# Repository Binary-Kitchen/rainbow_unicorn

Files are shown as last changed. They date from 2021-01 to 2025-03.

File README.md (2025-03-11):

# Rainbow Unicorn 1

## This repo is archived. New updated version here: https://github.com/blinkyparts/unicorn

This unicorn will bright up your life. The hair is glowing in all colours of the rainbow due to RGB-LEDs on the back. The soldering kit is very simple and easy to assamble.

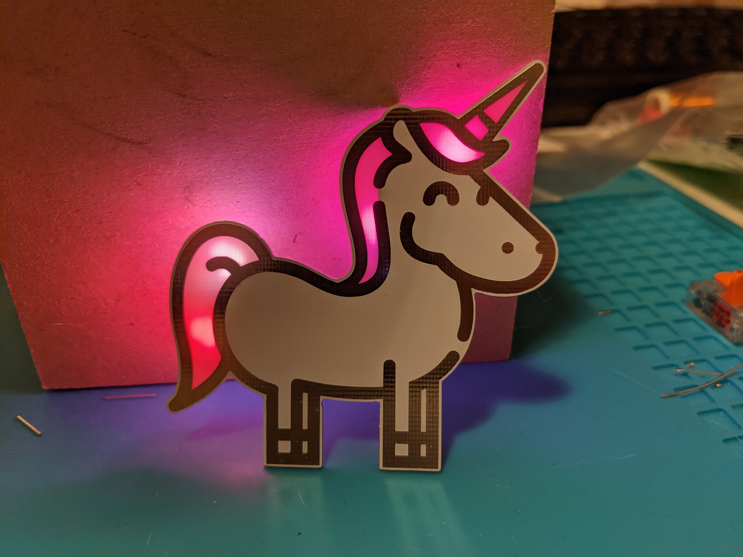
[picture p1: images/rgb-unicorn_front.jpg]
Rainbow Unicorn
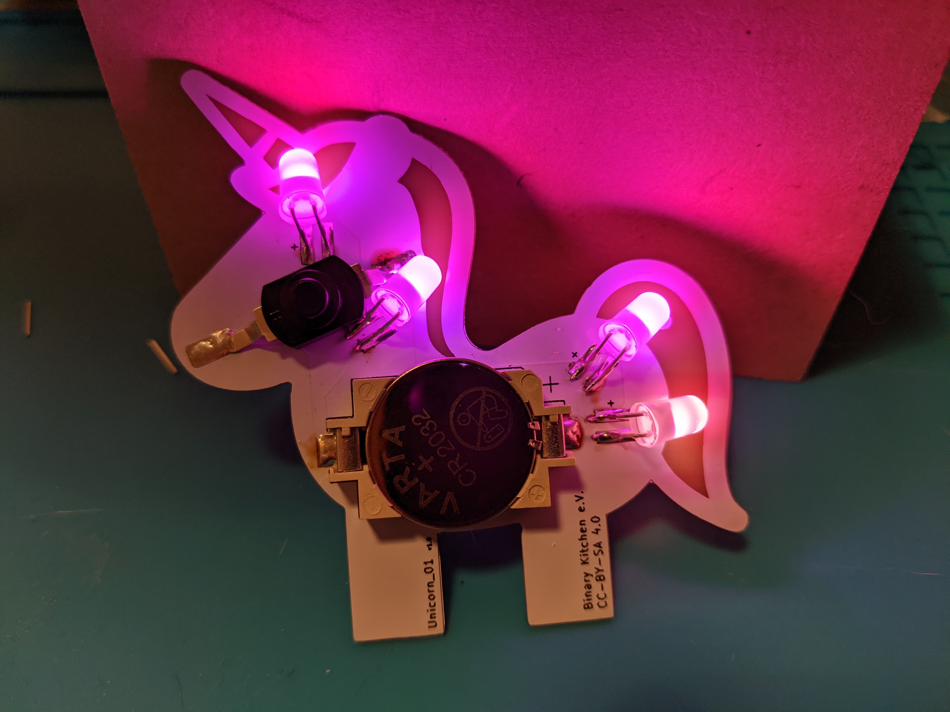
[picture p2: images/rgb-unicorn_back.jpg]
Rainbow Unicorn
 

The RGB-Effect looks like this, but much better in real :)
UniBadge 9x9 creation

- Status: **Complete**
- Difficulty: **2/5**

### Parts List

| Description | Quantity |
|---|---|
| RGB LEDs 5mm | 4 |
| Button (SMD) | 1 |
| CR2032 Battery Holder (SMD) | 1 |
| CR2032 Battery (not included) | 1 |

### Manual
You can find the manual and pictures of every step here: https://github.com/Binary-Kitchen/SolderingTutorial

### Copyright and Authorship

- Board: [CC-BY-SA 4.0](https://creativecommons.org/licenses/by-sa/4.0/) - Binary Kitchen e.V.
- Unicorn SVG [CC-BY-SA](https://creativecommons.org/licenses/by-sa/4.0/) - [Unicorn by Mooms from the Noun Project](https://thenounproject.com/term/unicorn/2061795/) (We've bought a licence, you should honor the artist work too!)
- Idea and scheme: [CC-BY-SA 4.0](https://creativecommons.org/licenses/by-sa/4.0/) - [Elektronikmuseum Tettnang](http://www.emuseum-tettnang.de/)

### Buy Soldering Kits
If you want to buy the parts and PCB for a soldering kit you can find everything here: [shop.blinkyparts.com](https://shop.blinkyparts.com/de/Regenbogen-Einhorn-Einfacher-Bausatz-fuer-einen-tollen-Anstecker/blink232242)

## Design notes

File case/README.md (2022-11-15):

# Case

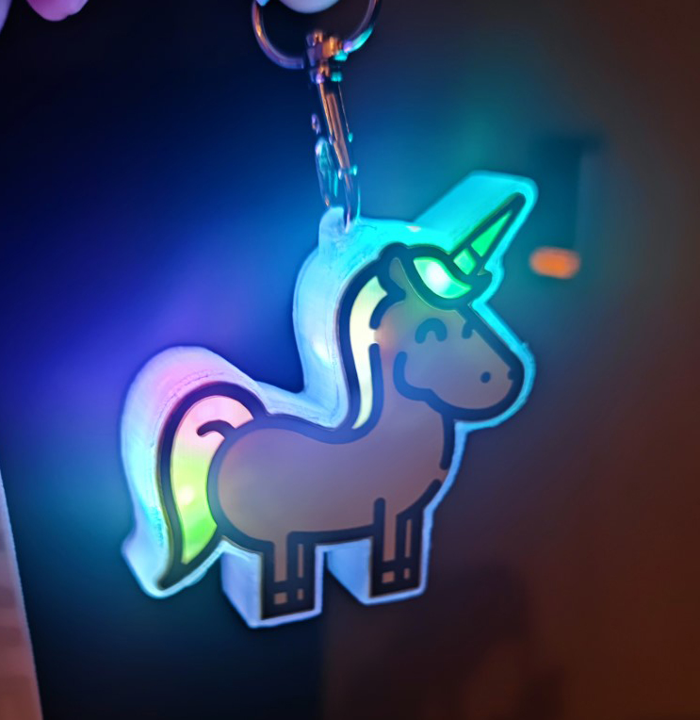
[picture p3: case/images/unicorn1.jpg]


It is recommented to print this case with transparent PET filament.

There are two variants of the case:

* A case consisting of a frame that will be glued to the board, and a separate lid held in place by screws.
* A case consisting of a single body part only, where the board just snaps in. This one is a bit easier to print and assemble, but not quite as sturdy.

## Case with Separate Lid

### Things you'll need

* Transparent Filament
* 6 M1,7*6 screws
* Glue

### Assembly

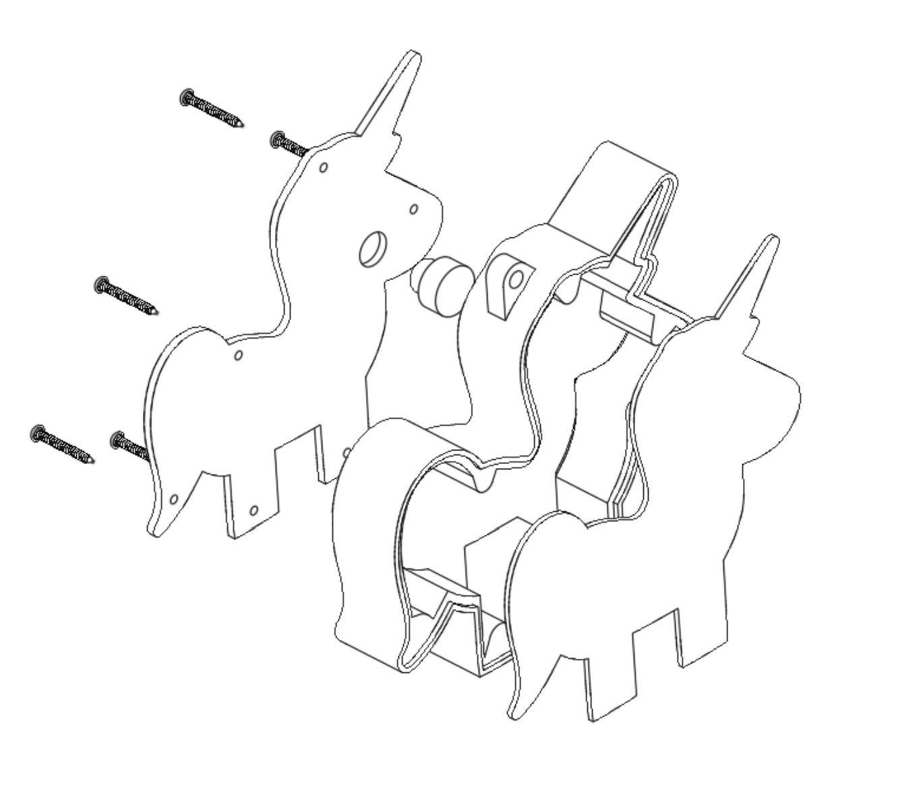
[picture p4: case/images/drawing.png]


First you'll need to print the three parts:

* Outer case
* Button
* Cover

I used generic PET filament at 235°C and a bed temperature of 75°C. Best is to place the case with the screw holes facing towards the build plate and adding a brim for more contact surface.

Then you can glue the PCB to the top part of the outer case. The top part does not have holes for the screws in it. I used hot glue, but the issue was, that the glue was getting hard too fast. I then heated up the PCB with my hot air gun to let the glue get soft again. After that I pressed the PCB and the case together. Maybe some other glue might work better.
With the PCB in place, just add place the button on top of the button on the PCB and carefully place the back cover on top of it. Fix the screws and your all set.

The result will look something like this:

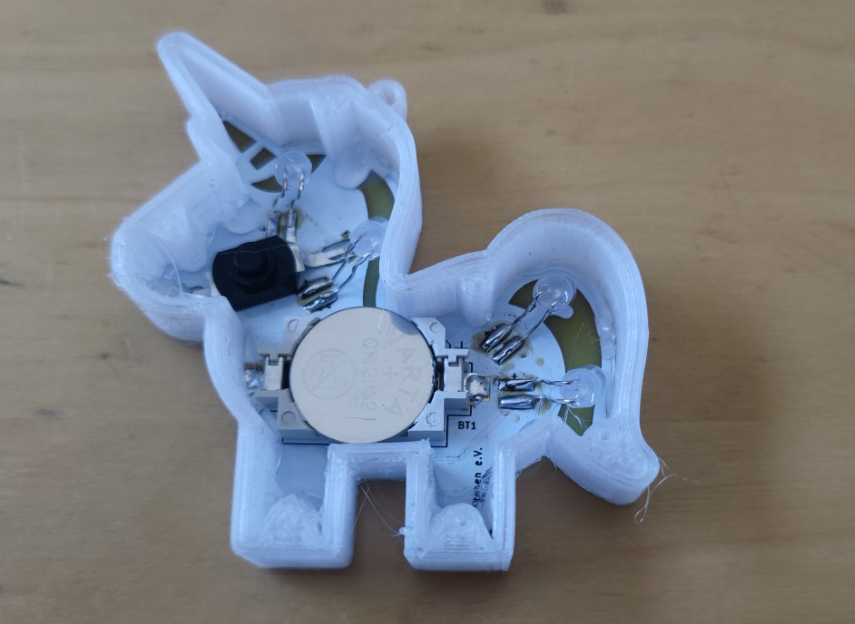
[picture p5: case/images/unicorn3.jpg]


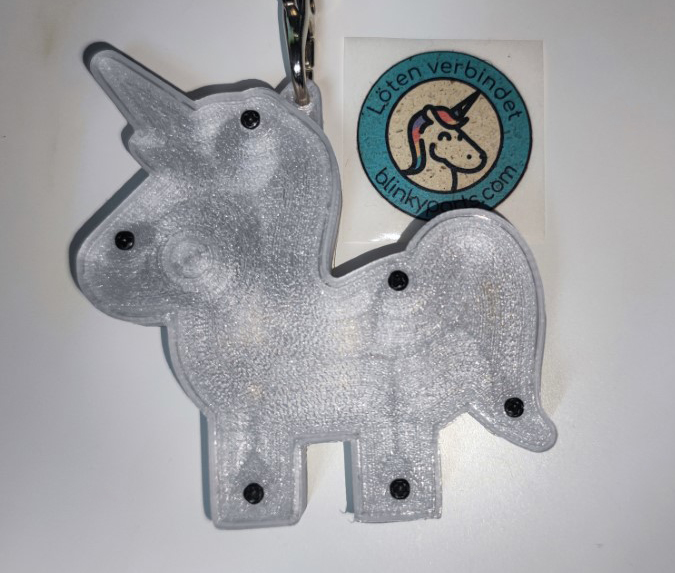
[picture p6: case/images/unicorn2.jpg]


## Snap-fit Case

### Things you'll need

* Transparent filament (preferably PET because it's a bit more flexible)

### Assembly

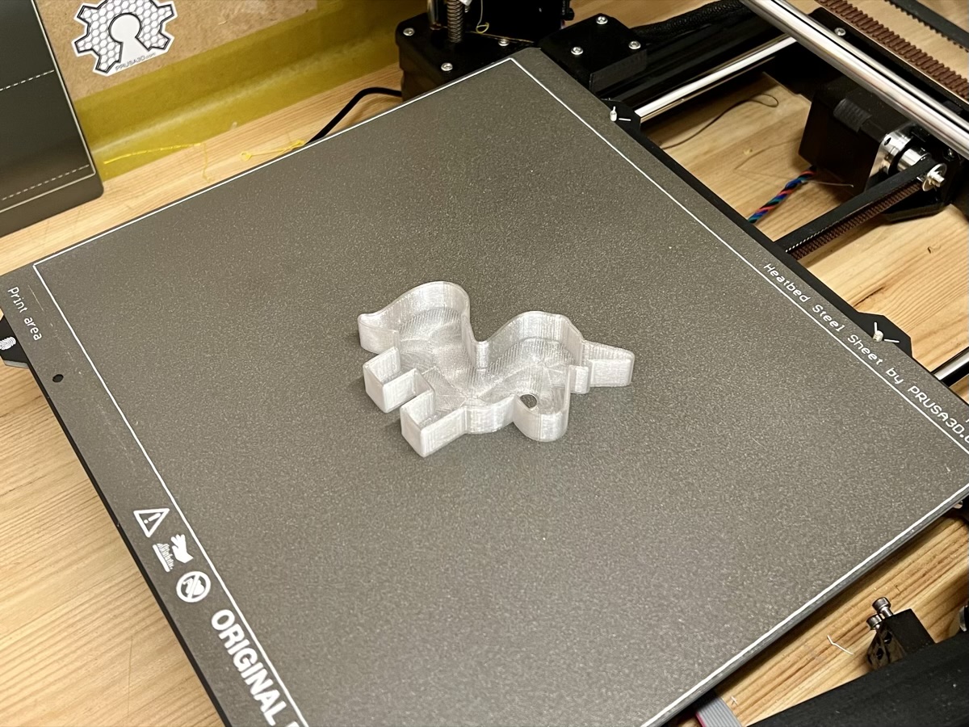
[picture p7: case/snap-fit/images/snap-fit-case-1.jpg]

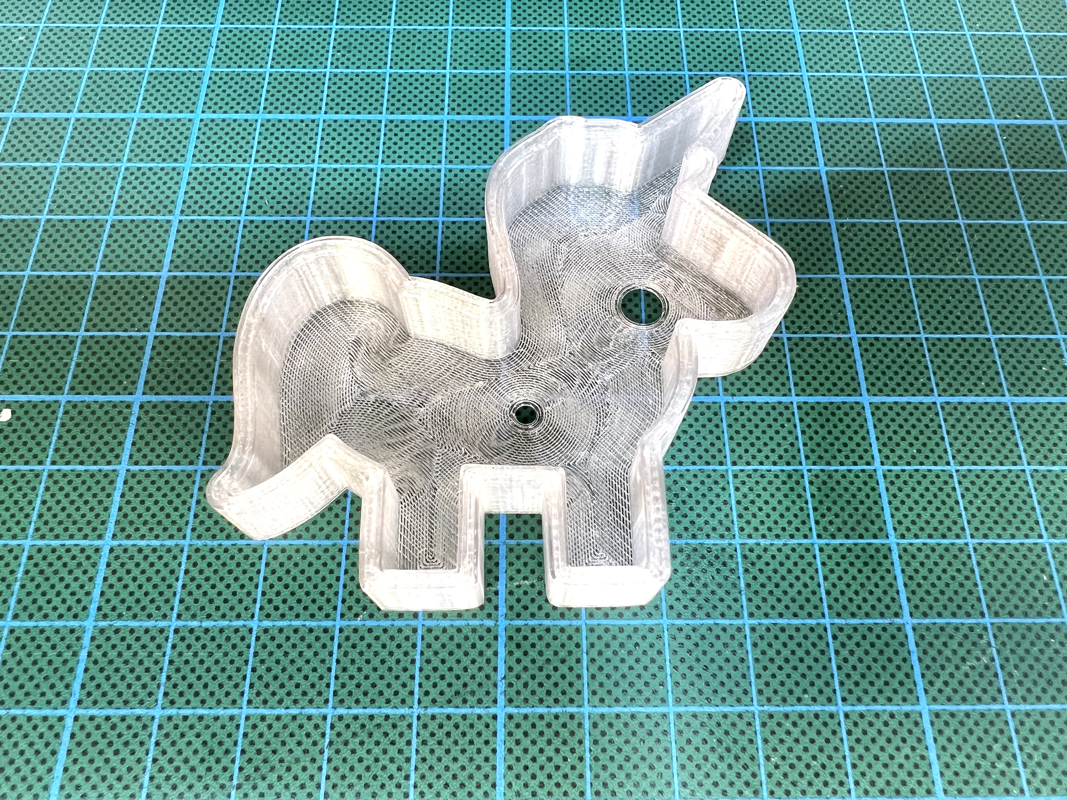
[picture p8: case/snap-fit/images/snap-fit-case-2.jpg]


You need to print the body (either the version with or without hanger) and the button. Print the body with the bottom side facing the print plate (like shown in the photo above), this way no support material and no brim is needed. Use two separate print jobs for body and button if you want to make sure that there is no stringing.

Using the "0.30mm DRAFT" preset in Prusa Slicer seems to work well and results in a print time of about 45 minutes. (I used "concentric" infill for the bottom layer to give it a more interesting look, but of course any infill pattern will work.)

After the print has completed simply insert the button into the hole and then snap the board into place, using gentle force as needed. The fit is rather tight to make sure the board is held in place securely.

If you want to remove the board later just insert a toothpick into the small hole on the back and push the board out.

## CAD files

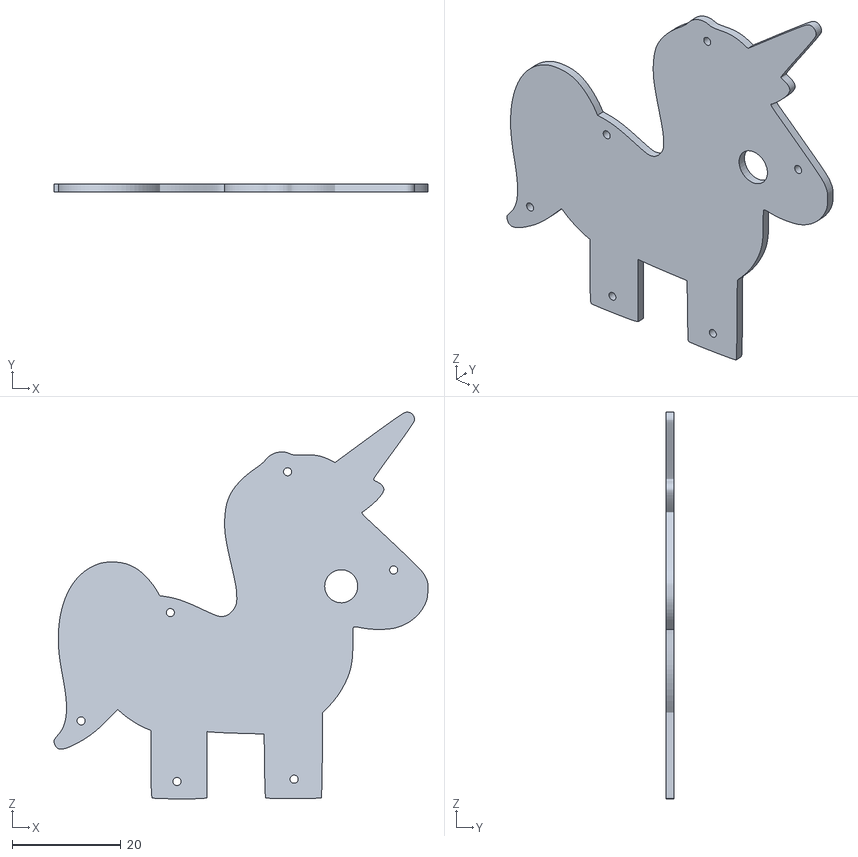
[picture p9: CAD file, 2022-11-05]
case/cover.stl
68.9 x 1.50 x 71.3

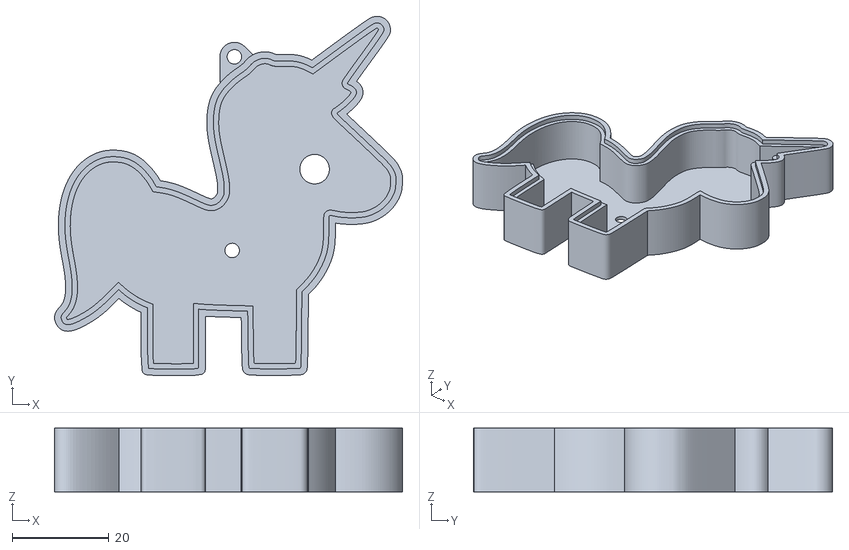
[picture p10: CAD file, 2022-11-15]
case/snap-fit/Case (with Hanger).stl
71.9 x 74.2 x 13.2

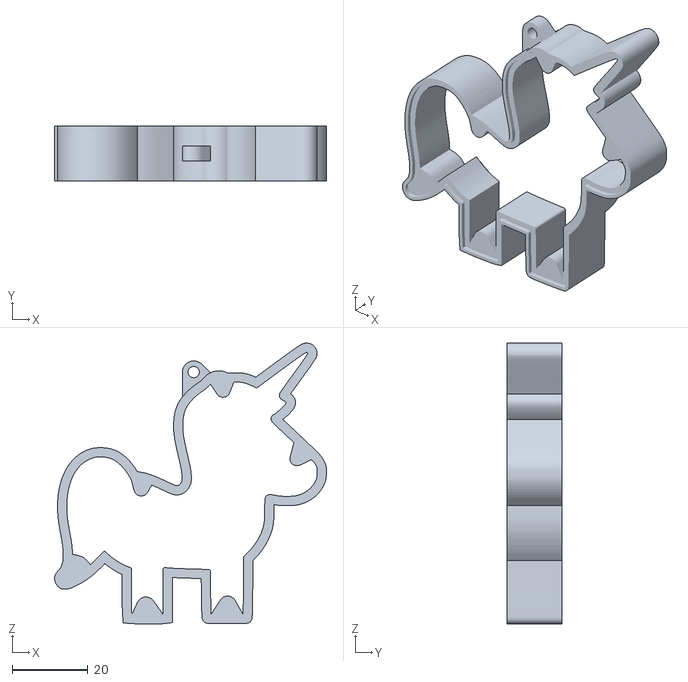
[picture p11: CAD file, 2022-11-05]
case/case.stl
71.9 x 14.5 x 74.2

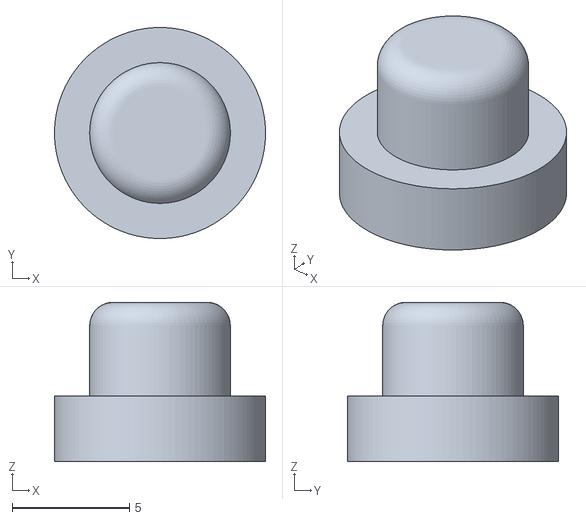
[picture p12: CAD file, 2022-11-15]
case/snap-fit/Button.stl
9.00 x 9.00 x 6.80

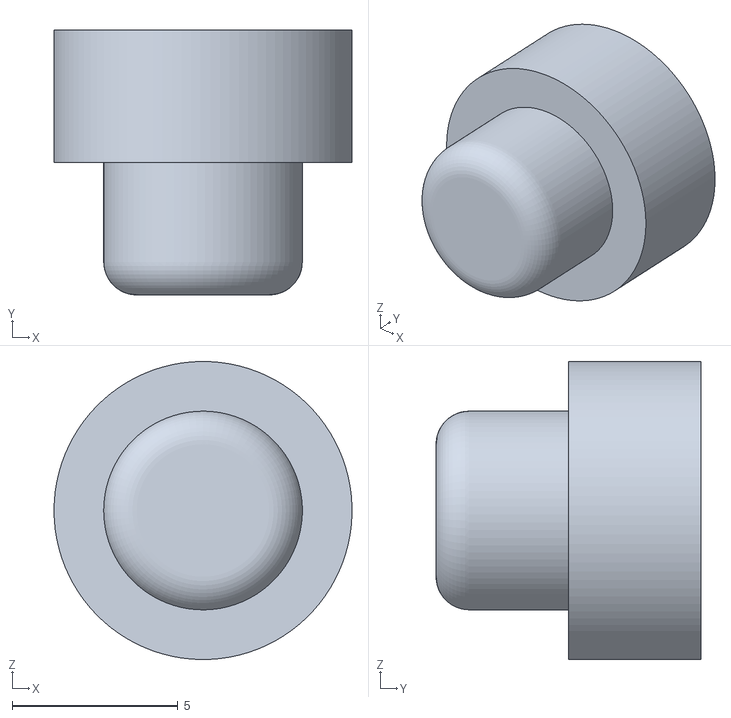
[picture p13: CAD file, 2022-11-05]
case/button.stl
9.00 x 8.00 x 9.00

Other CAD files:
case/snap-fit/Case (without Hanger).stl
case/Unicorn.f3d
case/snap-fit/Unicorn (snap fit).f3d

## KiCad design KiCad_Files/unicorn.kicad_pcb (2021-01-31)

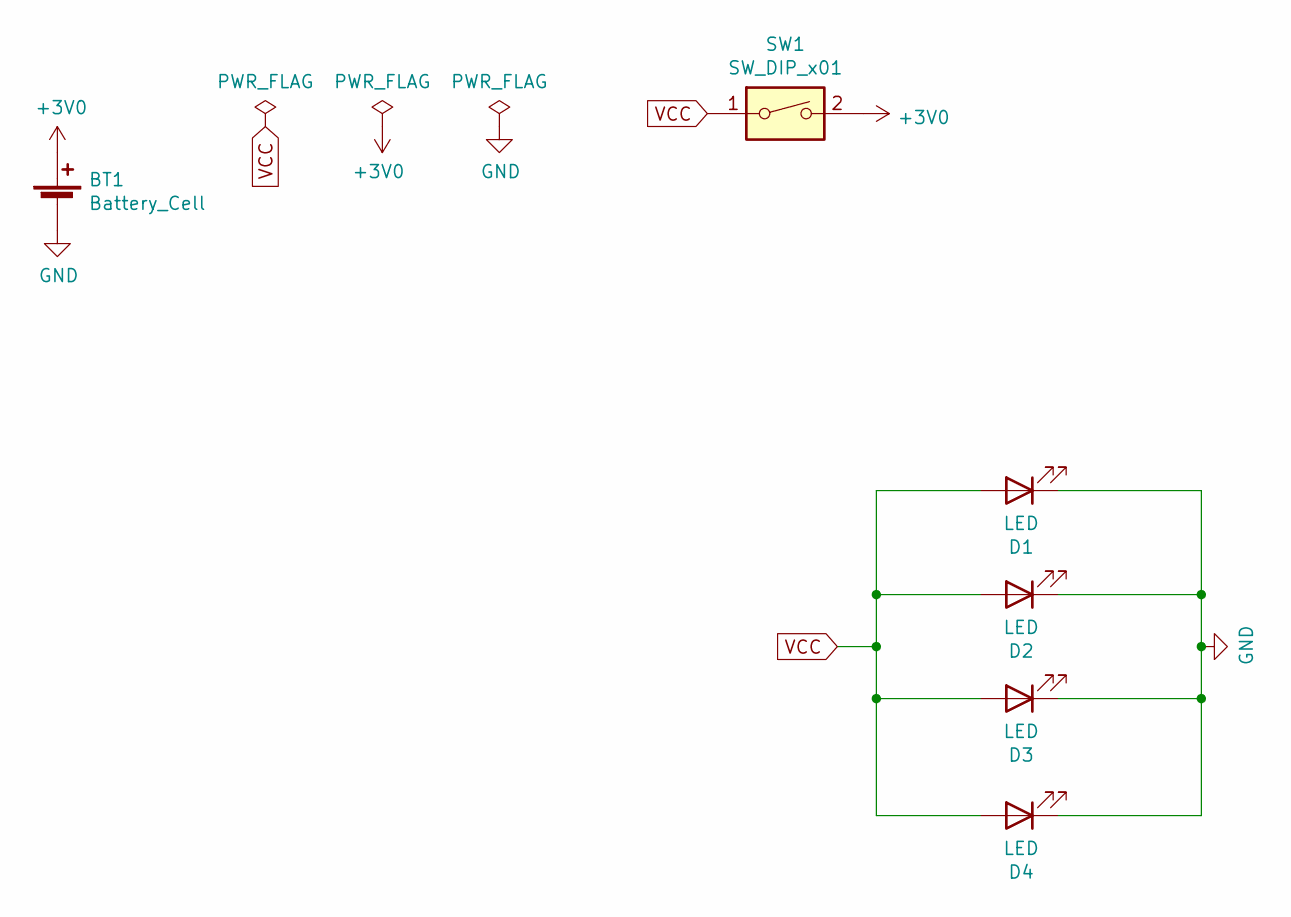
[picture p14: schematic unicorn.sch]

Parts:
BT1: Battery_Cell; BatteryHolder_Keystone_1060_1x2032
D1, D2, D3, D4: LED; 5mm_SMD-Pad
SW1: SW_DIP_x01; Push_Button

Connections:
+3V0: BT1.1 (+), SW1.2
GND: BT1.2 (-), D1.1 (K), D2.1 (K), D3.1 (K), D4.1 (K)
VCC: D1.2 (A), D2.2 (A), D3.2 (A), D4.2 (A), SW1.1

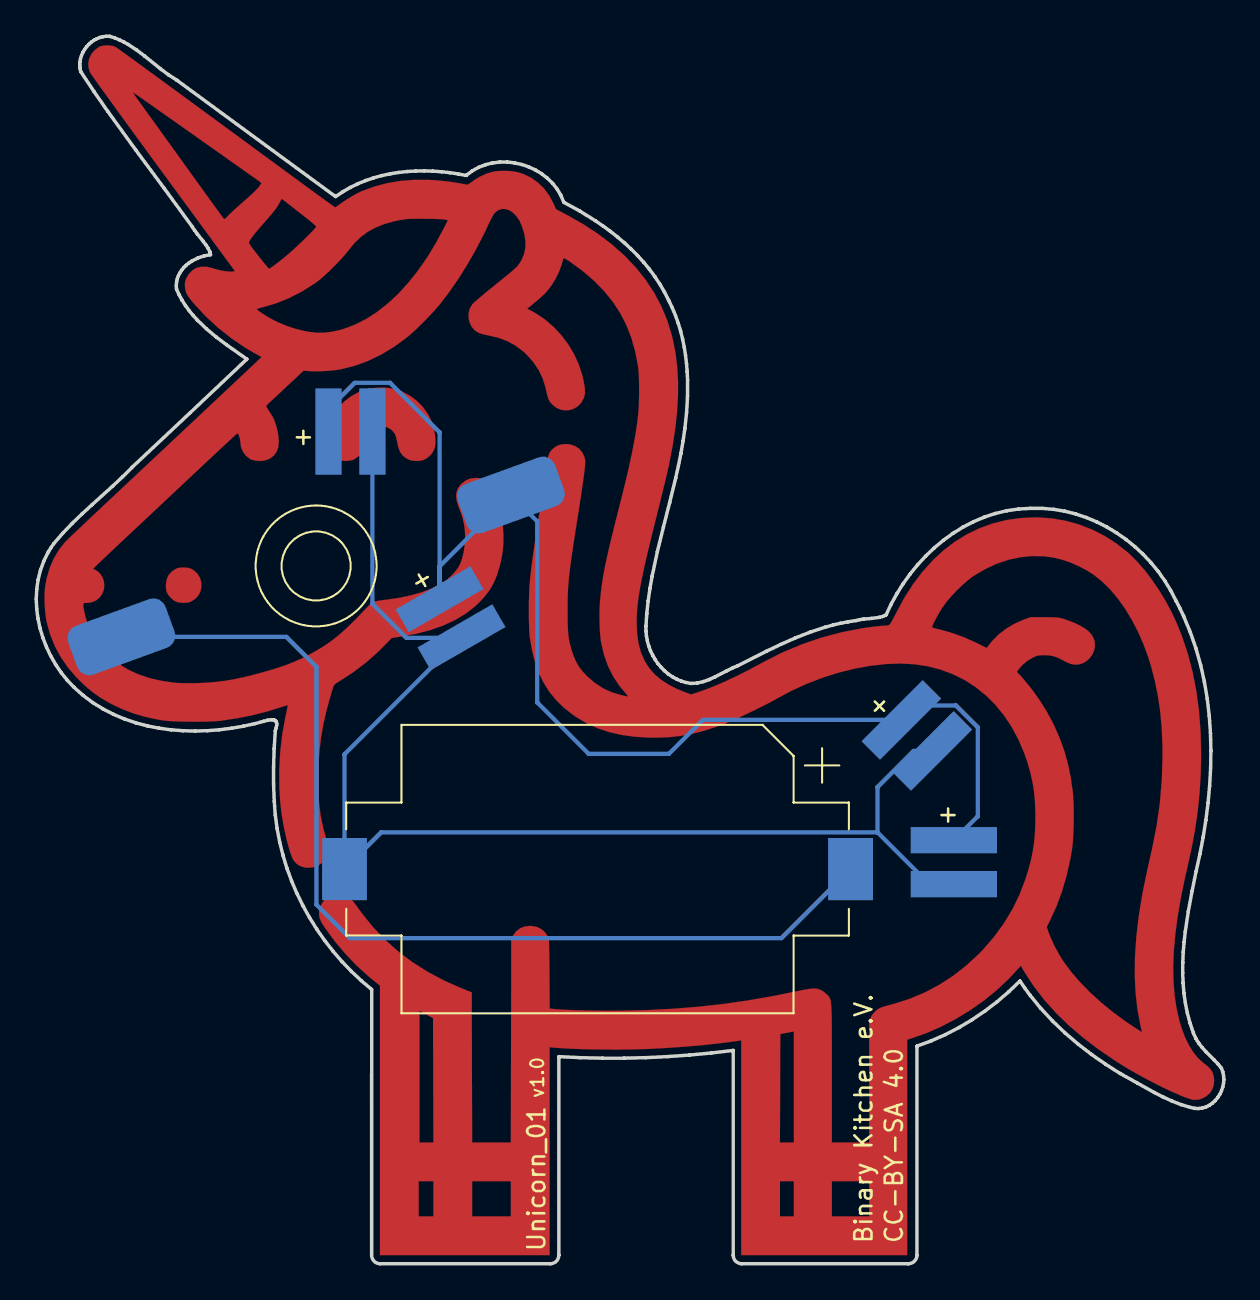
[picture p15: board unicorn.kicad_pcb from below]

Board: 2 copper layers, 68.8 x 71.1 mm, 7 parts (6 on the bottom side), 3 nets.

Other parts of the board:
Ref**: Val**; unicorn01

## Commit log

2021-01-31 inital commit
    [unicorn.kicad_pcb, unicorn.sch]
2022-11-03 feat: case for unicorn pcb
    [Unicorn.f3d, button.stl, case.stl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]
2022-11-13 Add alternative snap-fit version of the case
    [Button.stl, Case (with Hanger).stl, Case (without Hanger).stl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]
